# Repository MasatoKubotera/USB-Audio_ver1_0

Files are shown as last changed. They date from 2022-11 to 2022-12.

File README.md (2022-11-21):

<html lang="en">
  <head>
    <meta charset="uft-8">
    <meta name="author" content="Masato Kubotera">
  </head>
  <body>
    <h1>USB-Audio Ver. 1.0</h1>
    <h2>About USB-Audio</h2>
    <p>
      USB-Audio is the USB device for audio input/output via a USB interface.
      <br><br>
      <h3>About Ver. 1.0</h3>
      Ver 1.0 has one port for speaker output and two condenser microphones. Since it does not have a speaker, it must be connected via a 2-pin XH connector if necessary. <br>
      The device is used by connecting it to a PC with a USB Mini-B cable.<br>
      The outputs have 0 dB attenuation and the inputs have 3.5 -dB attenuation.
      Each input and output has an "MFB LP filter".
      <br><br>
      <!--
      -->
      <table>
        <tr>
          <td>
            <a href="image/brd_top.png">
              <div align="center">
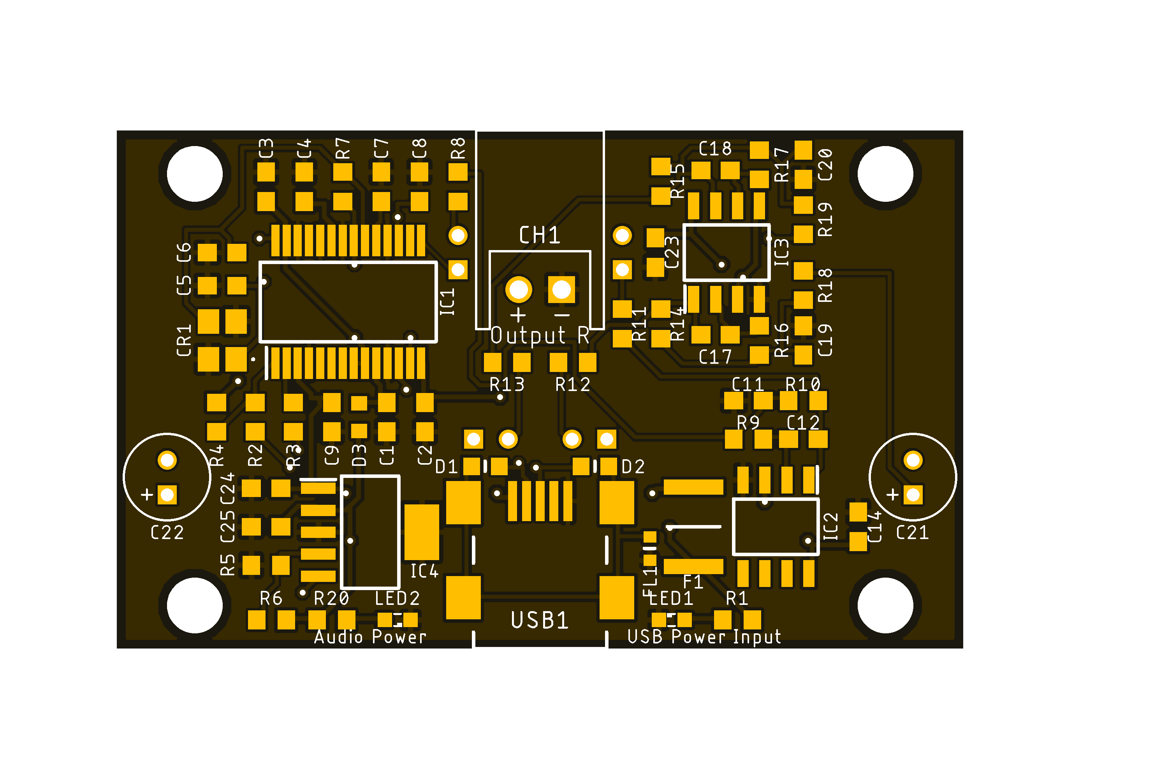
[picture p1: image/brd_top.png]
                
              </div>
            </a>
          </td>
          <td>
            <div align="center">
              
            </div>
          </td>
        </tr>
        <tr>
          <td>
            <div align="center">
              PCB preview image
            </div>
          </td>
          <td>
            <div align="center">
              After component mounting
            </div>
          </td>    
        </tr>
      </table>
    </p>
    <h2>Repository Contents</h2>
    <p>
    <dl>
      <dt>\image</dt>
      <dd>PCB preview images and capture of design screen</dd>
      <dt>\libraries</dt>
      <dd>Libraries used in Autodesk Eagle design</dd>
      <dt>Schematic.pdf</dt>
      <dd>Circuit diagram of this product</dd>
      <dt>BOM.txt</dt>
      <dd>Parts lists output from design data</dd>
      <dt>.brd</dt>
      <dd>Board wiring design file by Autodesk Eagle</dd>
      <dt>.sch</dt>
      <dd>Schematic design file by Autodesk Eagle</dd>
      <dt>Gerber_data.zip</dt>
      <dd>Zip folder of Gerber format files for PCB manufacturing requests.</dd>
      <dt>LICENSE</dt>
      <dd>This is a license to use this product. Please confirm before use.</dd>
      <dt>.gitignore</dt>
      <dd>File to exclude cache files from management.</dd>
    </dl>
    </p>
    <h2>Documentation</h2>
      <p>
        <h3>BOM</h3>
          <table>
            <thead>
              <tr>
                <th> Eagle Design Parts # </th>
                <th> Q'ty </th>
                <th> Mfr. Product # </th>
                <th> Supplier </th>
                <th> Description </th>
              </tr>
            </thead>
              <tr>
                <td>C1, C2, C3, C4, C7, C8, C9, C25</td>
                <td>8</td>
                <td>GRM188R71E105KA12</td>
                <td><a href="https://akizukidenshi.com/catalog/g/gP-14526/">Akizuki</a></td>
                <td>Multilayer Ceramic Capacitors SMD/SMT 1uF 25V 10% 0603</td>
              </tr>
              <tr>
                <td>C10, C13, C15, C16, C21, C22</td>
                <td>6</td>
                <td>UMW1V100MDD</td>
                <td><a href="https://akizukidenshi.com/catalog/g/gP-08377/">Akizuki</a></td>
                <td>Aluminum Electrolytic Capacitors - Radial Leaded 35volts 10uF 85c 5x5 2LS</td>
              </tr>
              <tr>
                <td>C11, C19, C20</td>
                <td>3</td>
                <td>GCD188R71H182KA01J</td>
                <td><a href="https://www.mouser.jp/ProductDetail/81-GCD188R71H182KA1J">Mouser</a></td>
                <td>Multilayer Ceramic Capacitors SMD/SMT 1800pF 50V 10% 0603</td>
              </tr>
              <tr>
                <td>C12, C17, C18</td>
                <td>3</td>
                <td>GRM1882C1H331JA01</td>
                <td><a href="https://akizukidenshi.com/catalog/g/gP-09254/">Akizuki</a></td>
                <td>Multilayer Ceramic Capacitors SMD/SMT 330pF 50V 5% 0603</td>
              </tr>
              <tr>
                <td>C14, C23</td>
                <td>2</td>
                <td>GRM188R6YA106MA73</td>
                <td><a href="https://akizukidenshi.com/catalog/g/gP-13161/">Akizuki</a></td>
                <td>Multilayer Ceramic Capacitors SMD/SMT 10uF 35V 20% 0603</td>
              </tr>
              <tr>
                <td>C24</td>
                <td>1</td>
                <td>GCM188L81H104K57</td>
                <td><a href="https://akizukidenshi.com/catalog/g/gP-16143/">Akizuki</a></td>
                <td>Multilayer Ceramic Capacitors SMD/SMT 0.1uF 50V 10% 0603</td>
              </tr>
              <tr>
                <td>C5, C6</td>
                <td>2</td>
                <td>C1608C0G1H220J080AA</td>
                <td><a href="https://www.mouser.jp/ProductDetail/810-C1608C0G1H220J">Mouser</a></td>
                <td>Multilayer Ceramic Capacitors SMD/SMT 22pF 50V 5% 0603</td>
              </tr>
              <tr>
                <td>CH1</td>
                <td>1</td>
                <td>S2B-XH-A(LF)(SN)</td>
                <td><a href="https://akizukidenshi.com/catalog/g/gC-12262/">Akizuki</a></td>
                <td>Connector Header Through Hole, Side entry 2 position 2.5mm</td>
              </tr>
              <tr>
                <td>CR1</td>
                <td>1</td>
                <td>FA-238V 12.0000MB-K3</td>
                <td><a href="https://akizukidenshi.com/catalog/g/gP-05225/">Akizuki</a></td>
                <td>Crystals 12.0000MHz 50ppm 10pF -40C +85C</td>
              </tr>
              <tr>
                <td>D1, D2</td>
                <td>2</td>
                <td>CG0603MLC-05E</td>
                <td><a href="https://www.mouser.jp/ProductDetail/652-CG0603MLC-05E">Mouser</a></td>
                <td>ESD Protectors 5V 0603</td>
              </tr>
              <tr>
                <td>D3</td>
                <td>1</td>
                <td>RB520SM-30T2R</td>
                <td><a href="https://www.mouser.jp/ProductDetail/755-RB520SM-30T2R">Mouser</a></td>
                <td>Schottky Diodes & Rectifiers Diode Schottky 30V 0.2A</td>
              </tr>
              <tr>
                <td>F1</td>
                <td>1</td>
                <td>MF-MSMF050-2</td>
                <td><a href="https://www.mouser.jp/ProductDetail/652-MF-MSMF050-2">Mouser</a></td>
                <td>PTC Resettable Fuses 15V .5A-HD 100A MAX</td>
              </tr>
              <tr>
                <td>FL1</td>
                <td>1</td>
                <td>BLM18SD220SN1D</td>
                <td><a href="https://www.mouser.jp/ProductDetail/81-BLM18SD220SN1D">Mouser</a></td>
                <td>Ferrite Beads 22 OHM 0603</td>
              </tr>
              <tr>
                <td>IC1</td>
                <td>1</td>
                <td>PCM2904DB</td>
                <td><a href="https://www.mouser.jp/ProductDetail/595-PCM2904DB">Mouser</a></td>
                <td>Interface - CODECs Ster Codec with USB Ifc Sngl-end I/O</td>
              </tr>
              <tr>
                <td>IC2, IC3</td>
                <td>2</td>
                <td>OPA2353UA</td>
                <td><a href="https://www.mouser.jp/ProductDetail/595-OPA2353UA">Mouser</a></td>
                <td>High Speed Operational Amplifiers Hi-Spd Single-Sply Rail-to-Rail</td>
              </tr>
              <tr>
                <td>IC4</td>
                <td>1</td>
                <td>REG103GA-AG4</td>
                <td><a href="https://www.mouser.jp/ProductDetail/595-REG103GA-AG4">Mouser</a></td>
                <td>LDO Voltage Regulators DMOS 500mA LDO Reg</td>
              </tr>
              <tr>
                <td>LED1, LED2</td>
                <td>2</td>
                <td>150060VS86000</td>
                <td><a href="https://www.mouser.jp/ProductDetail/710-150060VS86000">Mouser</a></td>
                <td>Standard LEDs - SMD Green 2V 20mA 573nm 0603</td>
              </tr>
              <tr>
                <td>MIC1, MIC2</td>
                <td>2</td>
                <td>C9767BB422LFP</td>
                <td><a href="https://akizukidenshi.com/catalog/g/gP-01810/">Akizuki</a></td>
                <td>2-wire Electret Condenser Microphone</td>
              </tr>
              <tr>
                <td>R1, R20</td>
                <td>2</td>
                <td>RC0603FR-101KL</td>
                <td><a href="https://www.mouser.jp/ProductDetail/603-RC0603FR-101KL">Mouser</a></td>
                <td>Thick Film Resistors - SMD 1 kOhms 100-200mW 1% 0603</td>
              </tr>
              <tr>
                <td>R11, R12, R13</td>
                <td>3</td>
                <td>RC0603FR-10100RL</td>
                <td><a href="https://www.mouser.jp/ProductDetail/603-RC0603FR-10100RL">Mouser</a></td>
                <td>Thick Film Resistors - SMD 100 Ohms 100-200mW 1% 0603</td>
              </tr>
              <tr>
                <td>R18, R19</td>
                <td>2</td>
                <td>RC0603FR-1018KL</td>
                <td><a href="https://www.mouser.jp/ProductDetail/603-RC0603FR-1018KL">Mouser</a></td>
                <td>Thick Film Resistors - SMD 18 kOhms 100-200mW 1% 0603</td>
              </tr>
              <tr>
                <td>R2, R3</td>
                <td>2</td>
                <td>RC0603FR-1022RL</td>
                <td><a href="https://www.mouser.jp/ProductDetail/603-RC0603FR-1022RL">Mouser</a></td>
                <td>Thick Film Resistors - SMD 22 Ohms 100-200mW 1% 0603</td>
              </tr>
              <tr>
                <td>R4</td>
                <td>1</td>
                <td>RC0603FR-101K5L</td>
                <td><a href="https://www.mouser.jp/ProductDetail/603-RC0603FR-101K5L">Mouser</a></td>
                <td>Thick Film Resistors - SMD 1.5 kOhms 100-200mW 1% 0603</td>
              </tr>
              <tr>
                <td>R5</td>
                <td>1</td>
                <td>RC0603FR-1313KL</td>
                <td><a href="https://www.mouser.jp/ProductDetail/603-RC0603FR-1313KL">Mouser</a></td>
                <td>Thick Film Resistors - SMD 13 kOhms 100-200mW 1% 0603</td>
              </tr>
              <tr>
                <td>R6</td>
                <td>1</td>
                <td>RC0603FR-1027KL</td>
                <td><a href="https://www.mouser.jp/ProductDetail/603-RC0603FR-1027KL">Mouser</a></td>
                <td>Thick Film Resistors - SMD 27 kOhms 100-200mW 1% 0603</td>
              </tr>
              <tr>
                <td>R7</td>
                <td>1</td>
                <td>RC0603FR-101ML</td>
                <td><a href="https://www.mouser.jp/ProductDetail/603-RC0603FR-101ML">Mouser</a></td>
                <td>Thick Film Resistors - SMD 1 MOhms 100-200mW 1% 0603</td>
              </tr>
              <tr>
                <td>R8, R10, R14, R15</td>
                <td>4</td>
                <td>RC0603FR-1312KL</td>
                <td><a href="https://www.mouser.jp/ProductDetail/603-RC0603FR-1312KL">Mouser</a></td>
                <td>Thick Film Resistors - SMD 12 kOhms 100-200mW 1% 0603</td>
              </tr>
              <tr>
                <td>R9, R16, R17</td>
                <td>3</td>
                <td>RC0603FR-103K9L</td>
                <td><a href="https://www.mouser.jp/ProductDetail/603-RC0603FR-103K9L">Mouser</a></td>
                <td>Thick Film Resistors - SMD 3.9 kOhms 100-200mW 1% 0603</td>
              </tr>
              <tr>
                <td>USB1</td>
                <td>1</td>
                <td>MUSB-5B-NE-S175</td>
                <td><a href="https://akizukidenshi.com/catalog/g/gC-05843/">Akizuki</a></td>
                <td>Mini USB Connector  5P B type, Female, SMT type, without standoff</td>
              </tr>
            <tbody>
          </table>          
        <h3>PCB Fabrication</h3>
          PCB(Printed Circuit Board) manufacturing was outsourced to <a href="https://www.elecrow.com/pcb-manufacturing.html">Elecrow</a>.<br>
          The custom specifications are as follows.
          <ul>
            <li>Layer : 2 layers</li>
            <li>Dimensions : 49 x 30</li>
            <li>Different PCB Design : 1eg</li>
            <li>PCB Thickness : 1.6</li>
            <li>PCB Color : Black</li>
            <li>Surface Finish : HASL</li>
            <li>Castellated Hole : No</li>
            <li>Copper Weight : 1oz</li>
            <li>PCB Stencil : Stencil 15cm X 15cm no frame</li>
            <li>Stencil Side : Top</li>
          </ul>
          The data used to order fabrication are as follows.
          <ul>
            <li>Eagle design rule : <a href="https://www.elecrow.com/download/Elecrow_PCB_eagle_rule.zip">Elecrow Eagle Design Rule</a></li>
            <li>Eagle CAM file : <a href="https://www.elecrow.com/download/Elecrow_Gerber_Generater_DrillAlign.zip">Elecrow CAM file</a></li>
            <li>Gerber format data : <a href="/Gerber_data.zip">Gerber_data.zip</a></li>
          </ul>
      </p>
    <h2>Reference</h2>
      <ul>
        <li>Texas Instruments PCM2904DB
          <ul>
            <li><a href="https://www.ti.com/lit/gpn/pcm2904">Stereo Audio CODEC with USB Interface, Single-Ended Analog Input/Output and S/PD datasheet (Rev. C)</a></li>
            <li><a href="https://www.ti.com/lit/pdf/sbfa020">Key Differences Between the PCM290x and PCM290xC</a></li>
        </ul>
        <li><a href="http://sim.okawa-denshi.jp/en/OPtazyuLowkeisan.htm">Multiple Feedback Low-pass Filter Design Tool</a></li>
      </ul>
    <h2>Contact</h2>
    <p>
    If you have any questions, please contact MasatoKubotera, the product's designer, by E-mail.<br>
    E-mail : <a href="mailto:masatokubotera06@yahoo.co.jp">masatokubotera06@yahoo.co.jp</a>
    </p>
    <h2>License Information</h2>
    <p>
      This product is open source.<br>
      Please review the <a href="/LICENSE">LICENSE file</a> for license information.<br>
      <br>
      <strong>USB-Audio Ver. 1.0</strong> by Masato Kubotera is licensed under a <a href="http://creativecommons.org/licenses/by-nc-sa/4.0/">Creative Commons Attribution-NonCommercial-ShareAlike 4.0 International License</a>.
    </p>    
  </body>
</html>

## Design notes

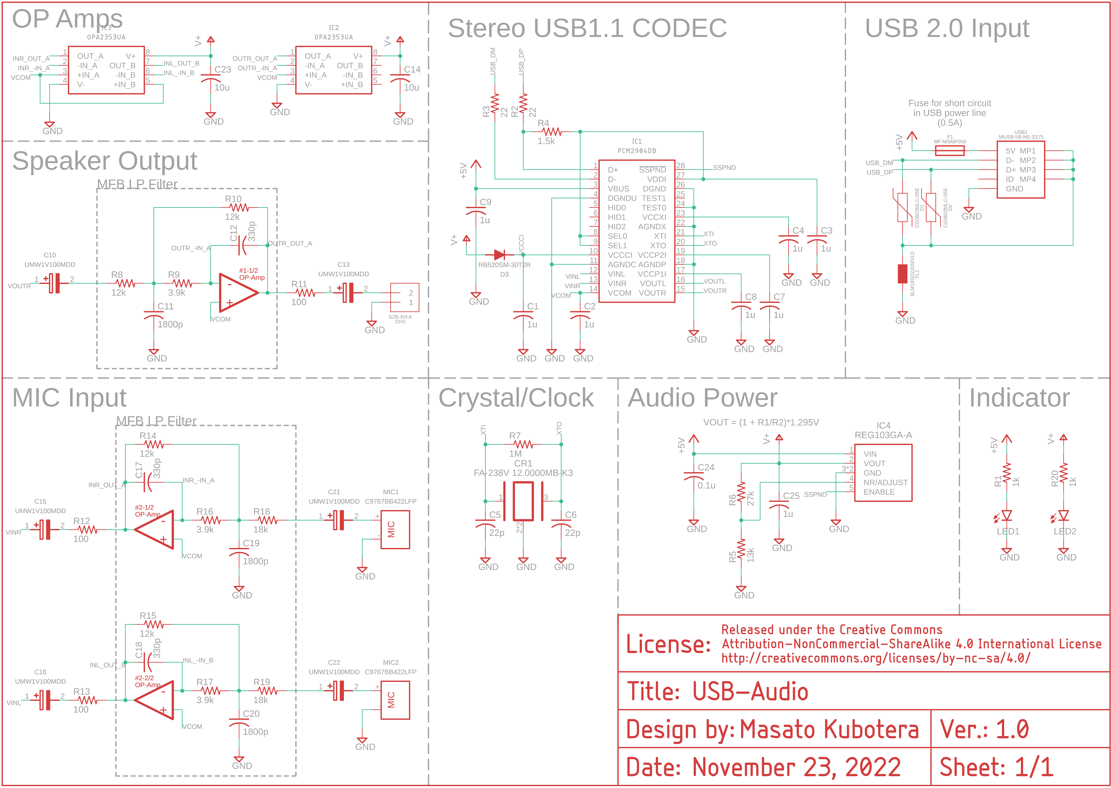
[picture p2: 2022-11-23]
image/sch.png

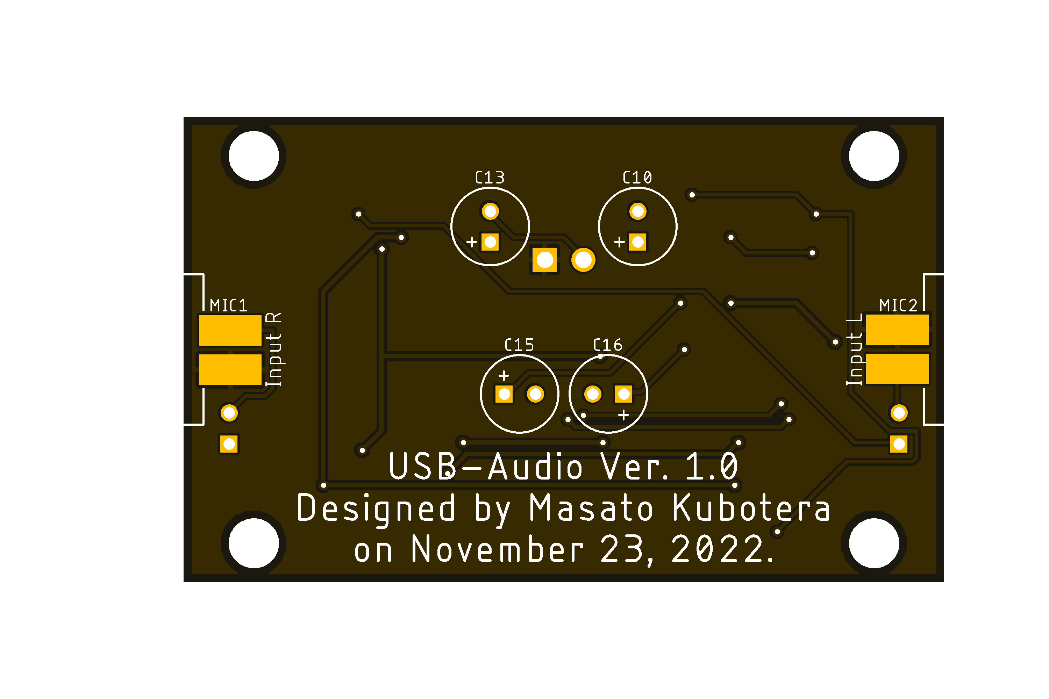
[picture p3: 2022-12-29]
image/brd_bottom.png

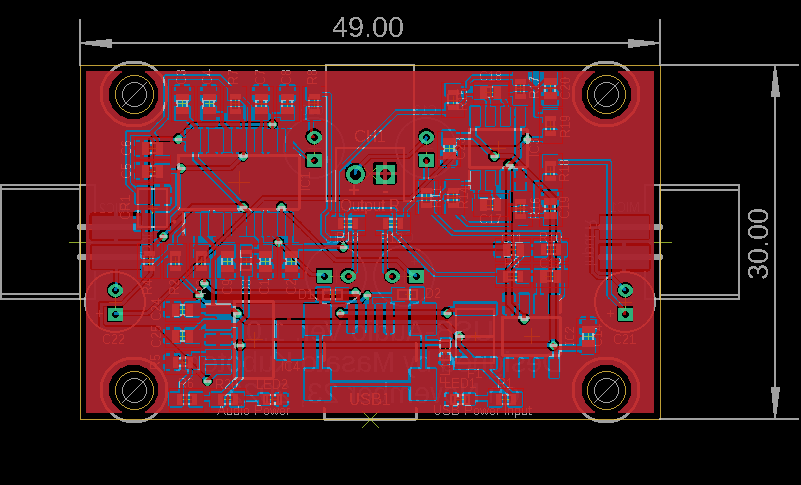
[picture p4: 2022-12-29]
image/brd.png

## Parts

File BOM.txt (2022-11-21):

Partlist exported from C:/Users/Masato/Documents/EAGLE/projects/USB-Audio_ver1_0/USB-Audio_ver_1_0.sch at 2022/11/11 22:42

Qty Value               Device              Package        Parts                           Description                
2                       LEDSML0603          SML0603        LED1, LED2                      LED                        
1   0.1u                C-USC1608           C1608          C24                             CAPACITOR, American symbol 
1   1.5k                R-US_R0603          R0603          R4                              RESISTOR, American symbol  
3   100                 R-US_R0603          R0603          R11, R12, R13                   RESISTOR, American symbol  
2   10u                 C-USC1608           C1608          C14, C23                        CAPACITOR, American symbol 
4   12k                 R-US_R0603          R0603          R8, R10, R14, R15               RESISTOR, American symbol  
1   13k                 R-US_R0603          R0603          R5                              RESISTOR, American symbol  
3   1800p               C-USC1608           C1608          C11, C19, C20                   CAPACITOR, American symbol 
2   18k                 R-US_R0603          R0603          R18, R19                        RESISTOR, American symbol  
1   1M                  R-US_R0603          R0603          R7                              RESISTOR, American symbol  
2   1k                  R-US_R0603          R0603          R1, R20                         RESISTOR, American symbol  
8   1u                  C-USC1608           C1608          C1, C2, C3, C4, C7, C8, C9, C25 CAPACITOR, American symbol 
2   22                  R-US_R0603          R0603          R2, R3                          RESISTOR, American symbol  
2   22p                 C-USC1608           C1608          C5, C6                          CAPACITOR, American symbol 
1   27k                 R-US_R0603          R0603          R6                              RESISTOR, American symbol  
3   3.9k                R-US_R0603          R0603          R9, R16, R17                    RESISTOR, American symbol  
3   330p                C-USC1608           C1608          C12, C17, C18                   CAPACITOR, American symbol 
1   BLM18SD220SN1D      BLM18SD220SN1D      BLM18SD220SN1D FL1                                                        
2   C9767BB422LFP       C9767BB422LFP       C9767BB422LFP  MIC1, MIC2                                                 
2   CG0603MLC-05E       CG0603MLC-05E       CG0603MLC-05E  D1, D2                                                     
1   FA-238V12.0000MB-K3 FA-238V12.0000MB-K3 FA238V         CR1                                                        
1   MF-MSMF050          MF-MSMF050          MF-MSMF050     F1                                                         
1   MINI_USB_B_SMD      MINI_USB_B_SMD      MINI_USB_B_SMD USB1                                                       
2   OPA2353UA           OPA2353UA           OPA2353UA      IC2, IC3                                                   
1   PCM2904DB           PCM2904DB           PCM2904DB      IC1                                                        
1   RB520SM-30T2R       RB520SM-30T2R       SOD-523-2      D3                                                         
1   REG103GA-A          REG103GA-A          SOT223-5       IC4                                                        
1   S2B-XH-A            S2B-XH-A            S2B-XH-A       CH1                                                        
6   UMW1V100MDD         UMW1V100MDD         UMW1V100MDD    C10, C13, C15, C16, C21, C22

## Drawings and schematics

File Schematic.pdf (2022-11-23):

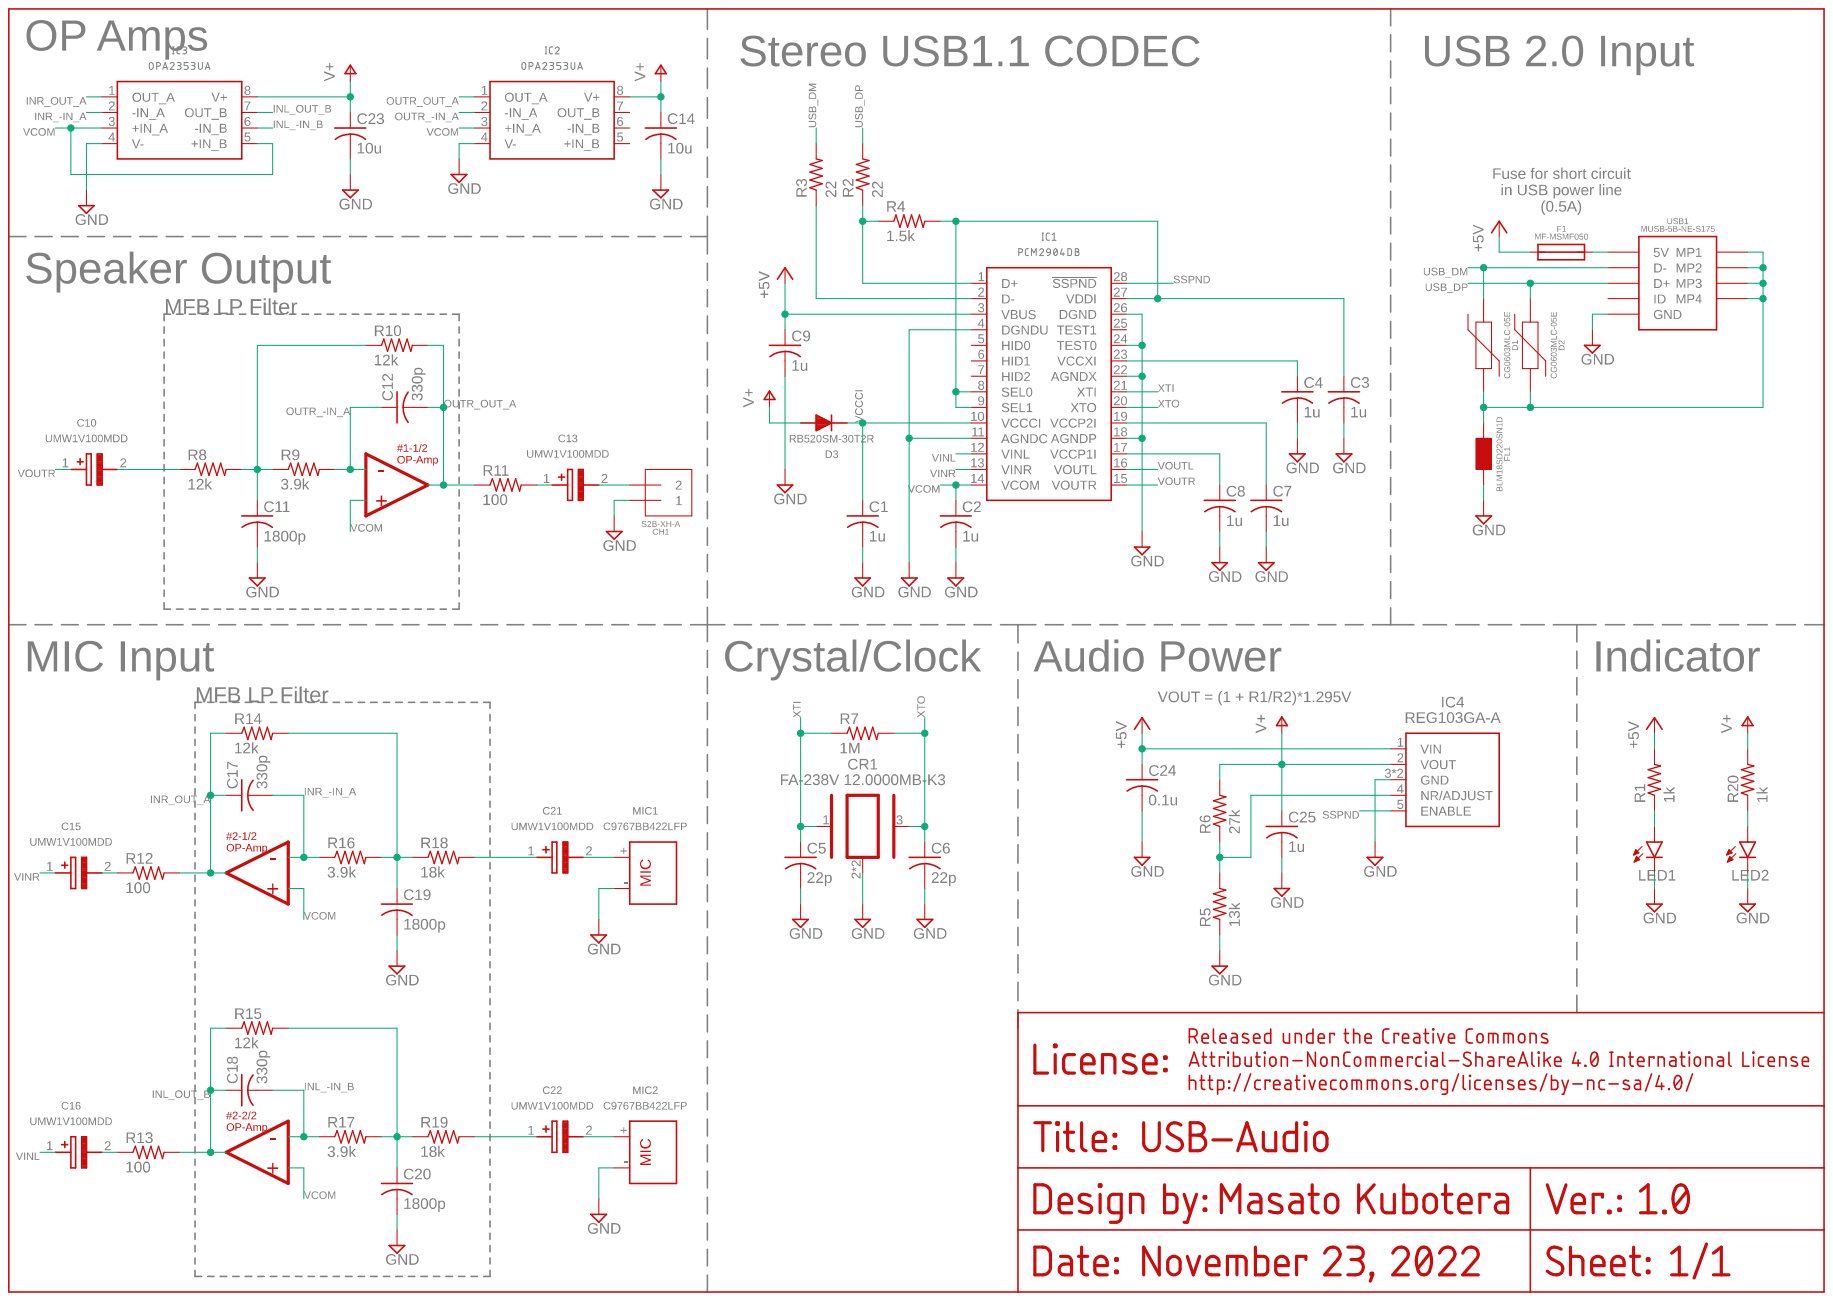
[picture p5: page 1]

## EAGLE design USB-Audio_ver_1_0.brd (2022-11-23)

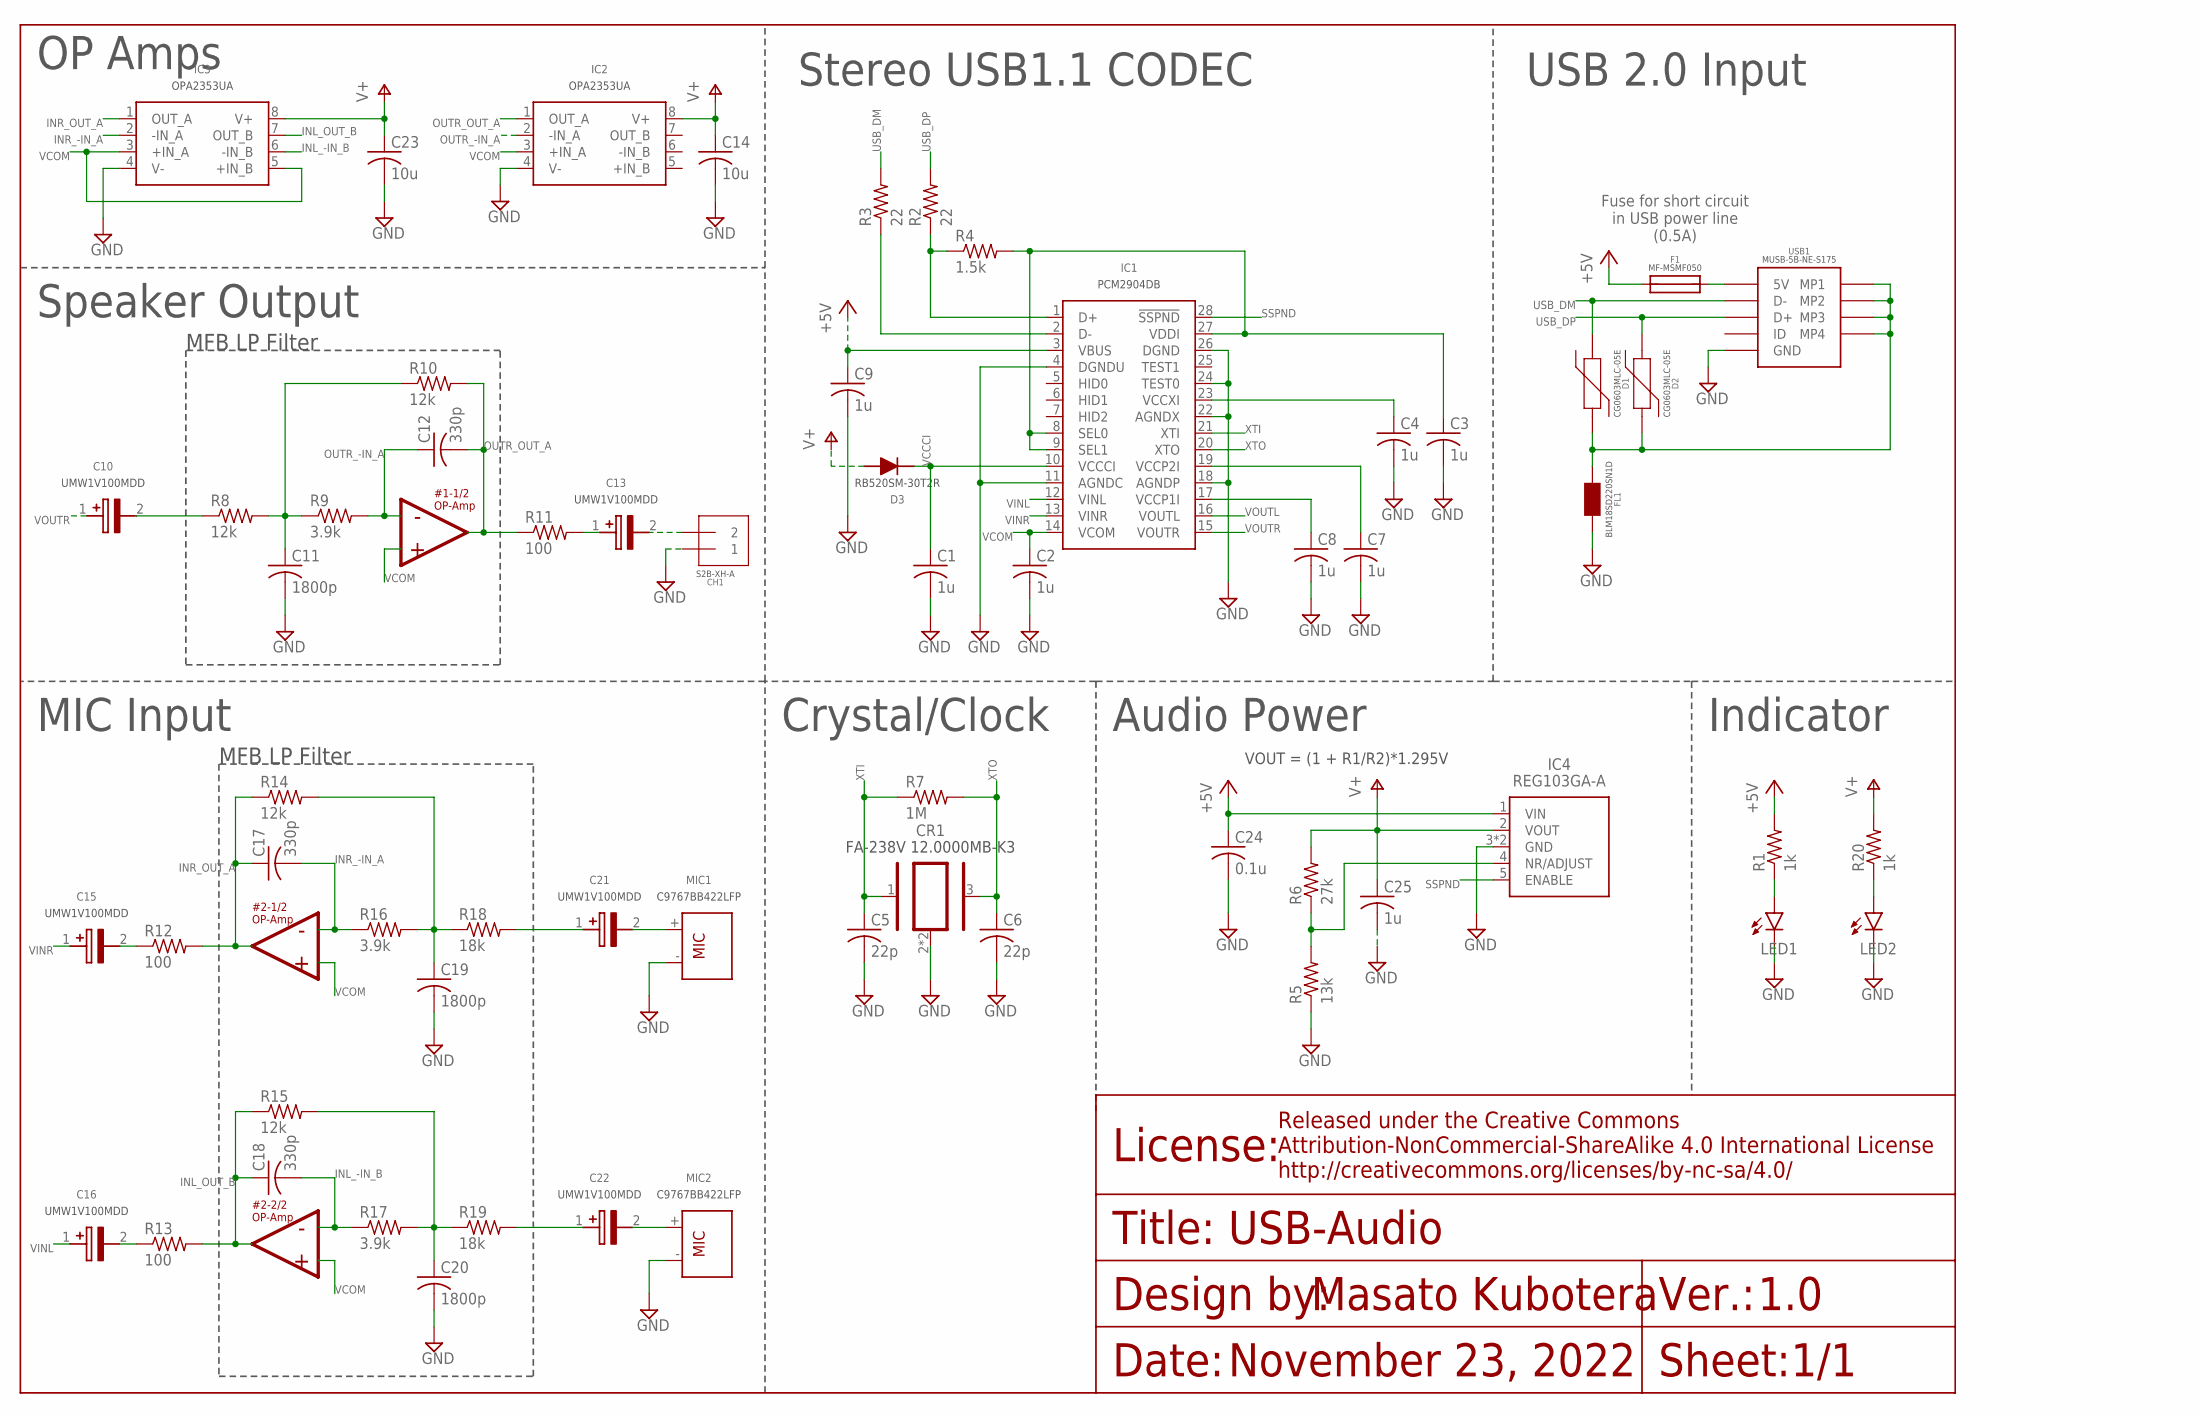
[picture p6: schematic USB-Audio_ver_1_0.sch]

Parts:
C1, C2, C3, C4, C7, C8, C9, C25: 1u; C1608
C5, C6: 22p; C1608
C10, C13, C15, C16, C21, C22: UMW1V100MDD
C11, C19, C20: 1800p; C1608
C12, C17, C18: 330p; C1608
C14, C23: 10u; C1608
C24: 0.1u; C1608
CH1: S2B-XH-A
CR1: FA-238V12.0000MB-K3; FA238V
D1, D2: CG0603MLC-05E
D3: RB520SM-30T2R; SOD-523-2
F1: MF-MSMF050
FL1: BLM18SD220SN1D
IC1: PCM2904DB
IC2, IC3: OPA2353UA
IC4: REG103GA-A; SOT223-5
LED1, LED2: LEDSML0603; SML0603
MIC1, MIC2: C9767BB422LFP
R1, R20: 1k; R0603
R2, R3: 22; R0603
R4: 1.5k; R0603
R5: 13k; R0603
R6: 27k; R0603
R7: 1M; R0603
R8, R10, R14, R15: 12k; R0603
R9, R16, R17: 3.9k; R0603
R11, R12, R13: 100; R0603
R18, R19: 18k; R0603
USB1: MINI_USB_B_SMD

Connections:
+5V: C9.1, C24.1, F1.1, IC1.3 (VBUS), IC4.1 (VIN), R1.2
B_FUSE_USB_MINI_B: F1.2, USB1.1 (5V)
DM: IC1.2 (D-), R3.1
DP: IC1.1 (D+), R2.1, R4.1
GND: C1.2, C2.2, C3.2, C4.2, C5.2, C6.2, C7.2, C8.2, C9.2, C11.2, C14.2, C19.2, C20.2, C23.2, C24.2, C25.2, CH1.1, CR1.2, CR1.4, FL1.2, IC1.4 (DGNDU), IC1.11 (AGNDC), IC1.18 (AGNDP), IC1.22 (AGNDX), IC1.24 (TEST0), IC1.26 (DGND), IC2.4 (V-), IC3.4 (V-), IC4.3 (GND), IC4.6 (GND), LED1.C, LED2.C, MIC1.-, MIC2.-, R5.1, USB1.5 (GND)
INL_-IN_B: C18.2, IC3.6 (-IN_B), R17.1
INL_OUT_B: C18.1, IC3.7 (OUT_B), R13.2, R15.1
INR_-IN_A: C17.2, IC3.2 (-IN_A), R16.1
INR_OUT_A: C17.1, IC3.1 (OUT_A), R12.2, R14.1
LED_USBIN: LED1.A, R1.1
LED_USBIN1: LED2.A, R20.1
MIC_INL: C22.2 (-), MIC2.+
MIC_INR: C21.2 (-), MIC1.+
unnamed: C15.2 (-), R12.1
unnamed: C7.1, IC1.19 (VCCP2I)
unnamed: C13.2 (-), CH1.2
unnamed: IC4.4 (NR/ADJUST), R5.2, R6.1
unnamed: C13.1 (+), R11.2
unnamed: C10.2 (-), R8.1
unnamed: C11.1, R8.2, R9.1, R10.1
unnamed: C16.2 (-), R13.1
unnamed: C19.1, R14.2, R16.2, R18.1
unnamed: C21.1 (+), R18.2
unnamed: C22.1 (+), R19.2
unnamed: C20.1, R15.2, R17.2, R19.1
OUTR_-IN_A: C12.1, IC2.2 (-IN_A), R9.2
OUTR_OUT_A: C12.2, IC2.1 (OUT_A), R10.2, R11.1
SSPND: C8.1, IC1.17 (VCCP1I), IC1.28 (!SSPND), IC4.5 (ENABLE)
USB_DM: D1.1, R3.2, USB1.2 (D-)
USB_DP: D2.1, R2.2, USB1.3 (D+)
USB_MINI_B_SHIELD: D1.2, D2.2, FL1.1, USB1.MP1, USB1.MP2, USB1.MP3, USB1.MP4
V+: C14.1, C23.1, C25.1, D3.2 (A), IC2.8 (V+), IC3.8 (V+), IC4.2 (VOUT), R6.2, R20.2
VCCCI: C1.1, D3.1 (K), IC1.10 (VCCCI)
VCCXI: C4.1, IC1.23 (VCCXI)
VCOM: C2.1, IC1.14 (VCOM), IC2.3 (+IN_A), IC3.3 (+IN_A), IC3.5 (+IN_B)
VDDI: C3.1, IC1.8 (SEL0), IC1.9 (SEL1), IC1.27 (VDDI), R4.2
VINL: C16.1 (+), IC1.12 (VINL)
VINR: C15.1 (+), IC1.13 (VINR)
VOUTL: IC1.16 (VOUTL)
VOUTR: C10.1 (+), IC1.15 (VOUTR)
XTI: C5.1, CR1.1, IC1.21 (XTI), R7.1
XTO: C6.1, CR1.3, IC1.20 (XTO), R7.2

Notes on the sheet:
1.0
1/1
November 23, 2022
USB-Audio
USB 2.0 Input
Fuse for short circuit in USB power line (0.5A)
VOUT = (1 + R1/R2)*1.295V
Audio Power
Stereo USB1.1 CODEC
MIC Input
Crystal/Clock
Speaker Output
#2-1/2 OP-Amp
#2-2/2 OP-Amp
MFB LP Filter
#1-1/2 OP-Amp
Indicator
OP Amps

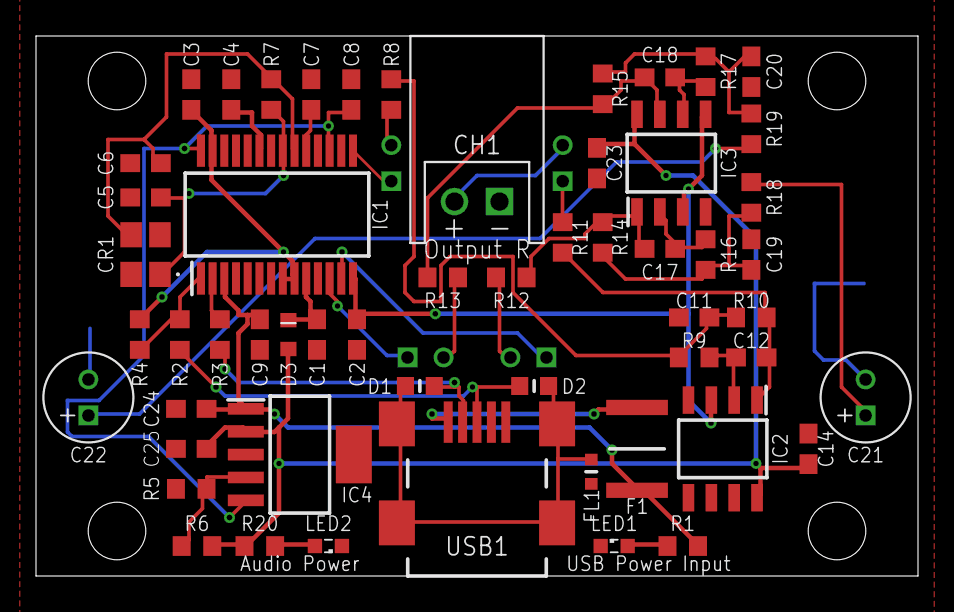
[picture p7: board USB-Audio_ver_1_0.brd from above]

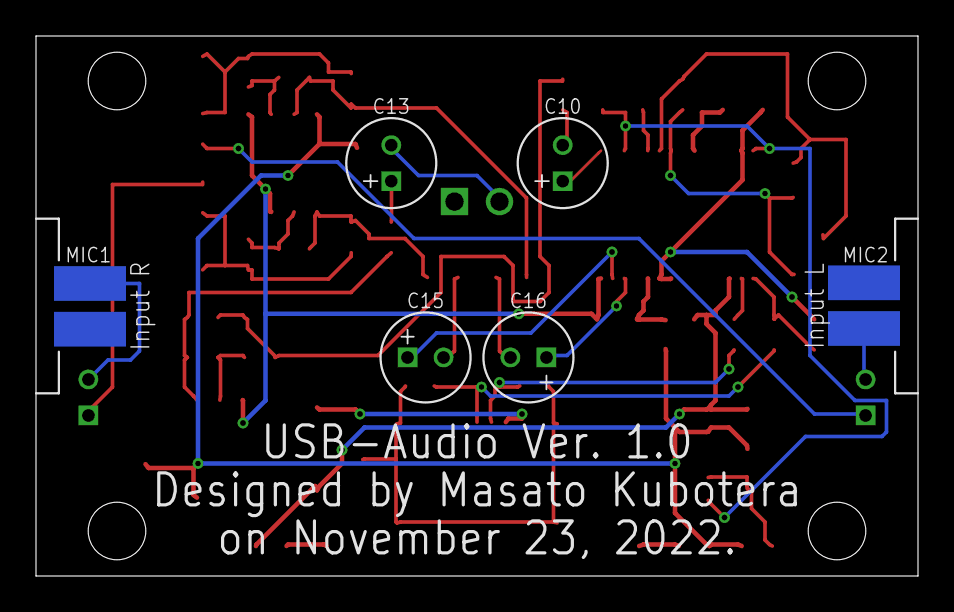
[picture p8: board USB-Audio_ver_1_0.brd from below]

Board: 2 copper layers, 49.0 x 30.0 mm, 61 parts (6 on the bottom side), 41 nets.

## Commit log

2022-11-21 Initial upload of data
    [USB-Audio_ver_1_0.brd, USB-Audio_ver_1_0.sch]
2022-11-23 Modified power supply and silk printing
    [USB-Audio_ver_1_0.brd, USB-Audio_ver_1_0.sch]

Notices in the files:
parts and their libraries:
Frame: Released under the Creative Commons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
